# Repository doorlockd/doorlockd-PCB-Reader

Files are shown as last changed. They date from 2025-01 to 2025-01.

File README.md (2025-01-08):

# Doorlockd card reader
This repository contains the design for a small PCB for an NFC card
reader to be used with the doorlockd door access system.

The PCB stacks on top of the the [Elechouse PN532 NFC reader
board](https://www.elechouse.com/product/pn532-nfc-rfid-module-v4/) and
adds indicator LEDs and a four-pin connector for a UART connection to
a controller.

This PCB is designed to be used with the [doorlockd hardware and
software](https://github.com/doorlockd/), but can also be used with any
other controller that can provide 5V and can talk over a UART.

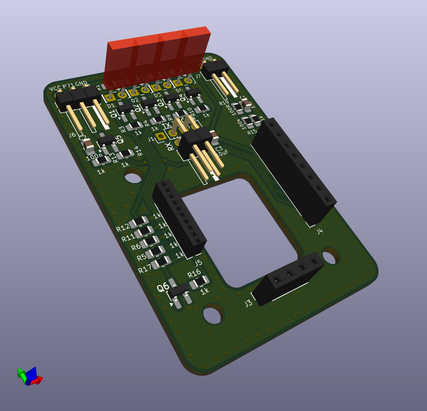
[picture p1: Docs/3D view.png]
3D rendering of PCB


In addition to the PCB, a 3D-printed case was made. Design files for
that will hopefully be published later.

See the [doorlockd organization page](https://github.com/doorlockd/) for
some photographs of the card reader PCB in practice.

## Features
This PCB provides:

 - UART connection the the PN532 board, using a square (2x2) connector
   with standard 2.54mm pitch. The square connector makes it easy to
   feed the cable through a round hole in e.g. a door frame.
 - Four indicator LEDs.
 - One open-drain output pin, to control external LEDs, a solenoid, etc.
 - One input pin, to read an external button, switch, etc.

The LEDs, output and input pin are driven/read by I/O pins on the PN532
NFC chip and can be individually controlled/read by sending the proper
commands via UART.

## License
Copyright 2021-2025 Matthijs Kooijman (matthijs@stdin.nl)

This source describes Open Hardware and is licensed under the CERN-OHL-P
v2 or any later version.

You may redistribute and modify this documentation and make products
using it under the terms of the CERN-OHL-P v2 (https:/cern.ch/cern-ohl).

This documentation is distributed WITHOUT ANY EXPRESS OR IMPLIED
WARRANTY, INCLUDING OF MERCHANTABILITY, SATISFACTORY QUALITY AND FITNESS
FOR A PARTICULAR PURPOSE. Please see the CERN-OHL-P v2 for applicable
conditions

See LICENSE.txt for the full license text.

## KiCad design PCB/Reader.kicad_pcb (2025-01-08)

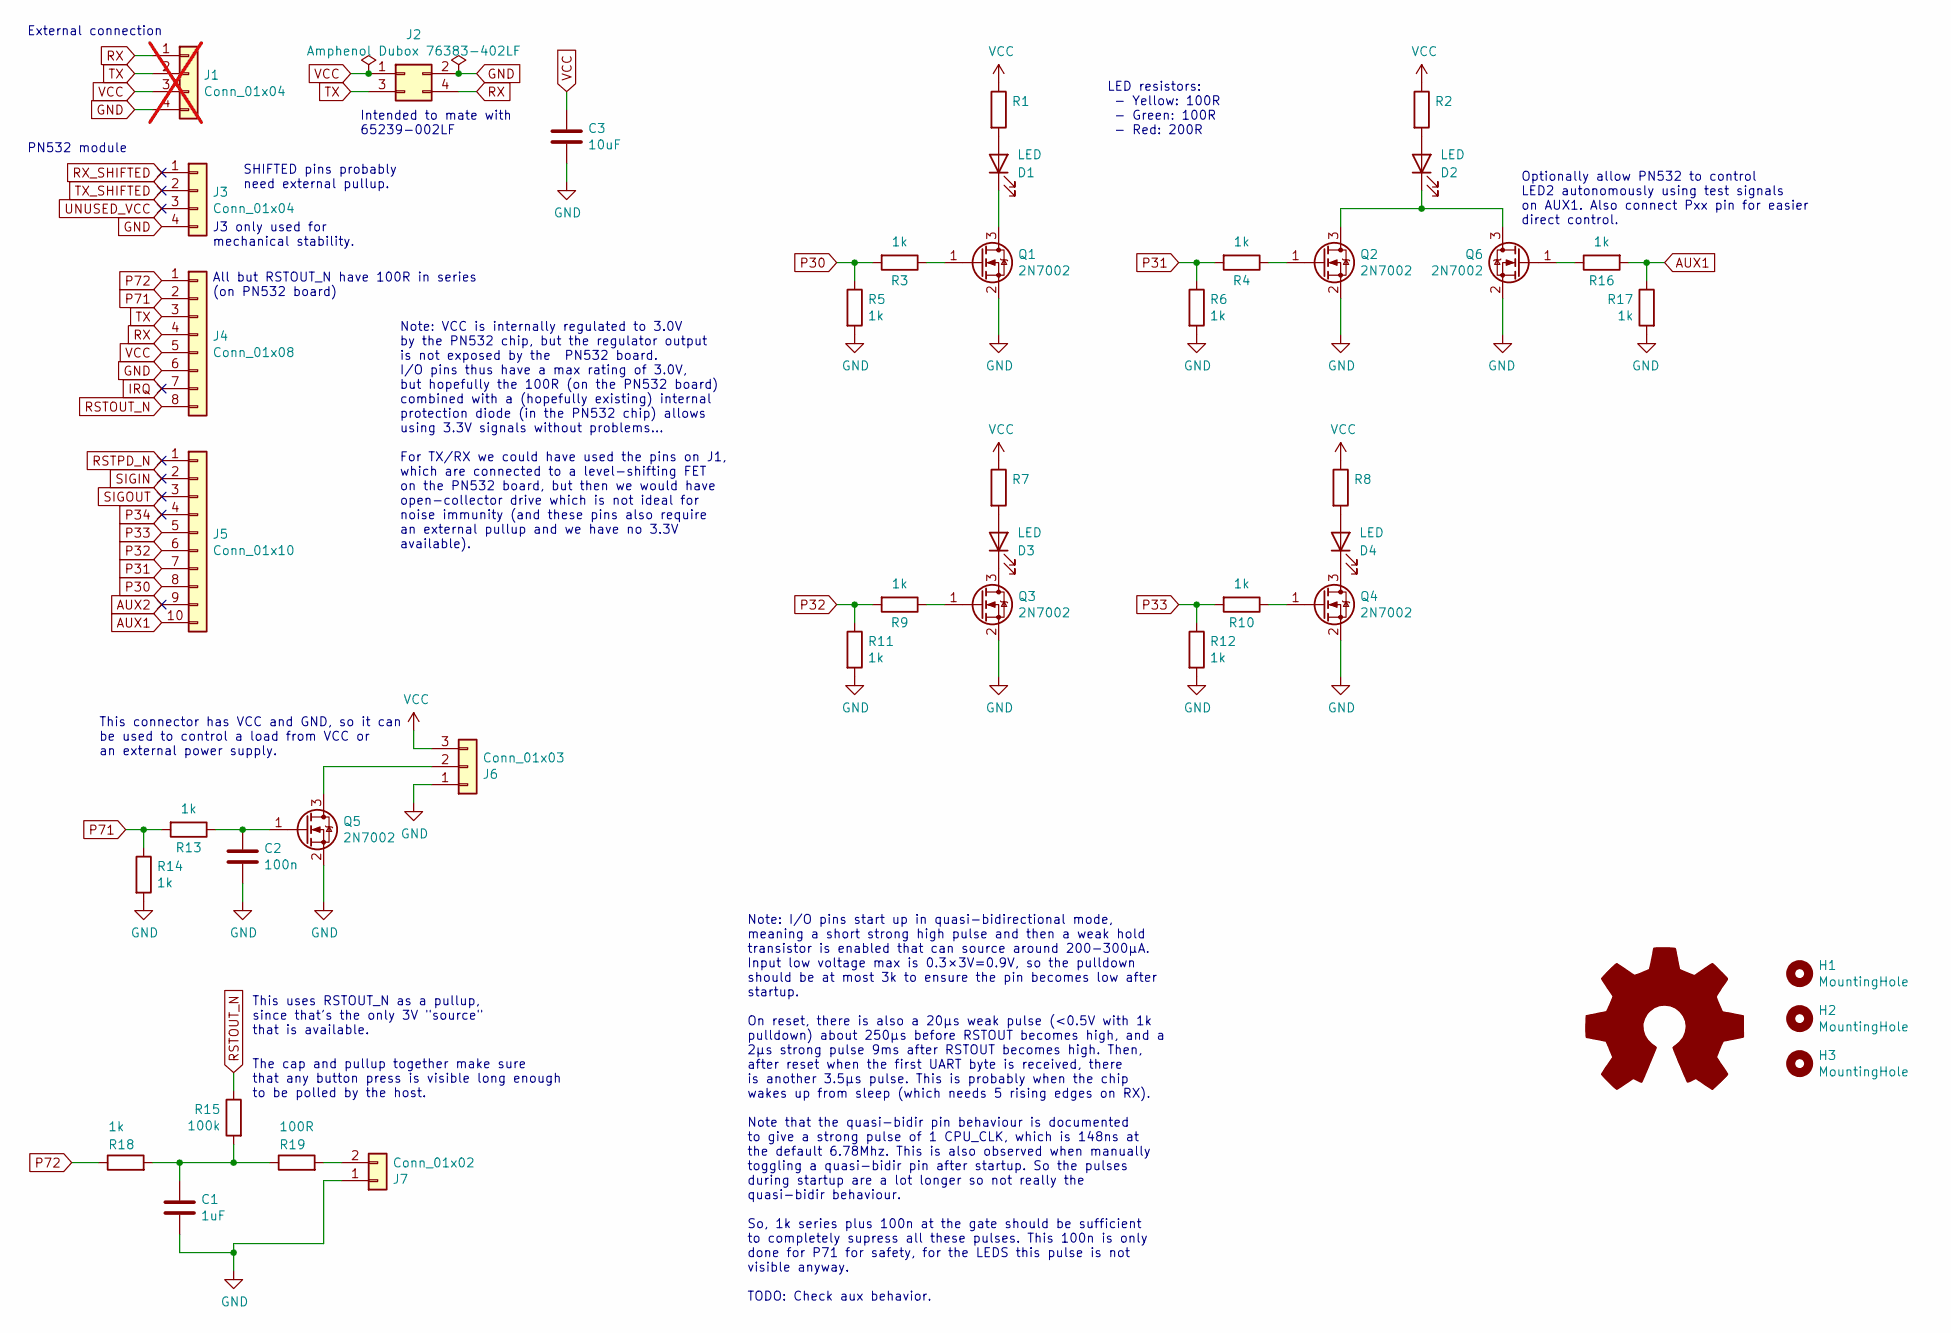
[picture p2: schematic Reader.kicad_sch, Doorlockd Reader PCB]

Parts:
C1: 1uF; C_0805_2012Metric_Pad1.18x1.45mm_HandSolder
C2: 100n; C_0805_2012Metric_Pad1.18x1.45mm_HandSolder
C3: 10uF; C_0805_2012Metric_Pad1.18x1.45mm_HandSolder
D1, D2, D3, D4: LED; LED_Rectangular_W5.0mm_H2.0mm
H1, H2, H3: MountingHole; MountingHole_3.2mm_M3
J1: Conn_01x04; PinHeader_1x04_P2.54mm_Vertical; not fitted
J2: Amphenol Dubox ‎76383-402LF‎; PinHeader_2x02_P2.54mm_Horizontal
J3: Conn_01x04; PinSocket_1x04_P2.54mm_Vertical
J4: Conn_01x08; PinSocket_1x08_P2.54mm_Vertical
J5: Conn_01x10; PinSocket_1x10_P1.27mm_Vertical
J6: Conn_01x03; PinHeader_1x03_P2.54mm_Horizontal
J7: Conn_01x02; PinHeader_1x02_P2.54mm_Horizontal
LOGO1: Logo_Open_Hardware_Large; OSHW-Symbol_8.9x8mm_SilkScreen
Q1, Q2, Q3, Q4, Q5, Q6: 2N7002; SOT-23_Handsoldering
R1, R2, R7, R8: R_0805_2012Metric_Pad1.20x1.40mm_HandSolder
R3, R4, R5, R6, R9, R10, R11, R12, R13, R14, R16, R17, R18: 1k; R_0805_2012Metric_Pad1.20x1.40mm_HandSolder
R15: 100k; R_0805_2012Metric_Pad1.20x1.40mm_HandSolder
R19: 100R; R_0805_2012Metric_Pad1.20x1.40mm_HandSolder

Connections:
AUX1: J5.10, R16.2, R17.1
AUX2: J5.9
GND: C1.2, C2.2, C3.2, J1.4, J2.2, J3.4, J4.6, J6.1, J7.1, Q1.2 (S), Q2.2 (S), Q3.2 (S), Q4.2 (S), Q5.2 (S), Q6.2 (S), R5.2, R6.2, R11.2, R12.2, R14.2, R17.2
IRQ: J4.7
unnamed: C1.1, R15.2, R18.2, R19.1
unnamed: D1.2 (A), R1.2
unnamed: D1.1 (K), Q1.3 (D)
unnamed: D2.2 (A), R2.2
unnamed: D2.1 (K), Q2.3 (D), Q6.3 (D)
unnamed: D3.2 (A), R7.2
unnamed: D3.1 (K), Q3.3 (D)
unnamed: D4.2 (A), R8.2
unnamed: D4.1 (K), Q4.3 (D)
unnamed: J6.2, Q5.3 (D)
unnamed: J7.2, R19.2
unnamed: Q1.1 (G), R3.1
unnamed: Q2.1 (G), R4.1
unnamed: Q3.1 (G), R9.1
unnamed: Q4.1 (G), R10.1
unnamed: C2.1, Q5.1 (G), R13.1
unnamed: Q6.1 (G), R16.1
P30: J5.8, R3.2, R5.1
P31: J5.7, R4.2, R6.1
P32: J5.6, R9.2, R11.1
P33: J5.5, R10.2, R12.1
P34: J5.4
P71: J4.2, R13.2, R14.1
P72: J4.1, R18.1
RSTOUT_N: J4.8, R15.1
RSTPD_N: J5.1
RX: J1.1, J2.4, J4.4
RX_SHIFTED: J3.1
SIGIN: J5.2
SIGOUT: J5.3
TX: J1.2, J2.3, J4.3
TX_SHIFTED: J3.2
UNUSED_VCC: J3.3
VCC: C3.1, J1.3, J2.1, J4.5, J6.3, R1.1, R2.1, R7.1, R8.1

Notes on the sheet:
This connector has VCC and GND, so it can be used to control a load from VCC or an external power supply.
Note: VCC is internally regulated to 3.0V by the PN532 chip, but the regulator output is not exposed by the PN532 board. I/O pins thus have a max rating of 3.0V, but hopefully the 100R (on the PN532 board) combined with a (hopefully existing) internal protection diode (in the PN532 chip) allows usi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
LED resistors: - Yellow: 100R - Green: 100R - Red: 200R
Optionally allow PN532 to control LED2 autonomously using test signals on AUX1. Also connect Pxx pin for easier direct control.
This uses RSTOUT_N as a pullup, since that's the only 3V "source" that is available.
PN532 module
SHIFTED pins probably need external pullup.
The cap and pullup together make sure that any button press is visible long enough to be polled by the host.
Note: I/O pins start up in quasi-bidirectional mode, meaning a short strong high pulse and then a weak hold transistor is enabled that can source around 200-300μA. Input low voltage max is 0.3×3V=0.9V, so the pulldown should be at most 3k to ensure the pin becomes low after startup. On reset, there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
J3 only used for mechanical stability.
Intended to mate with 65239-002LF
All but RSTOUT_N have 100R in series (on PN532 board)
External connection

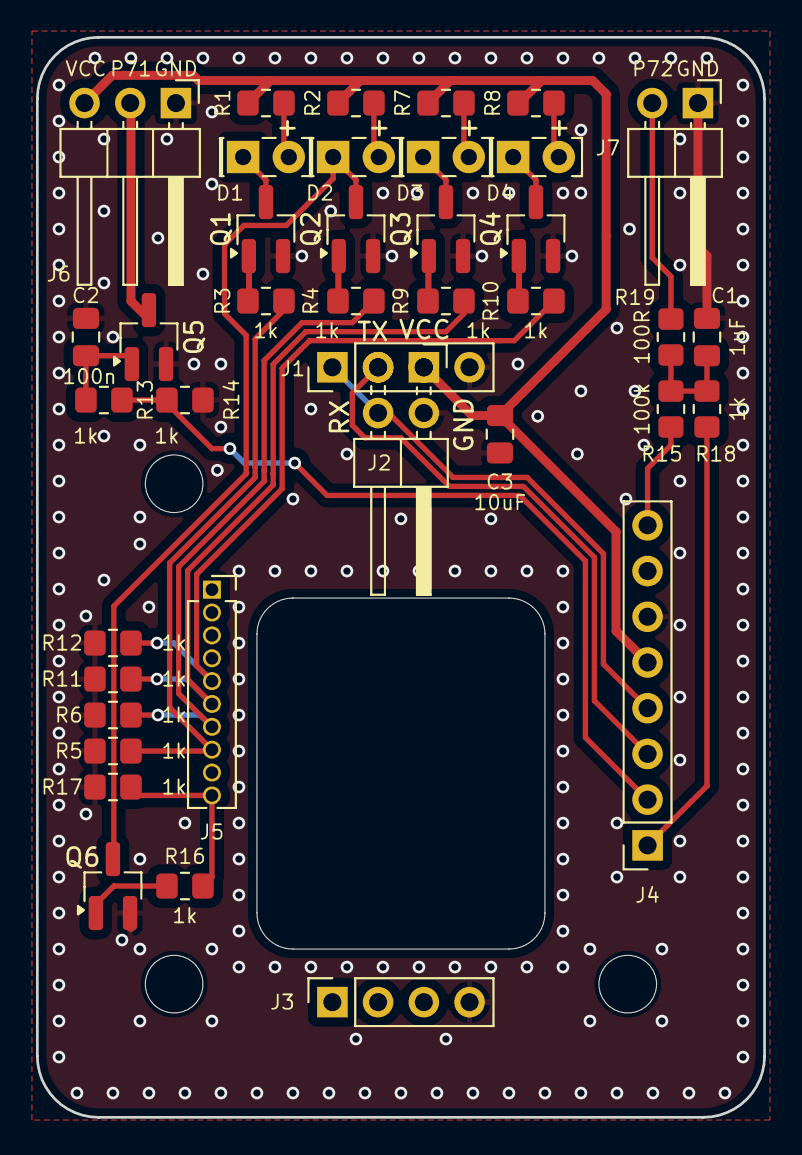
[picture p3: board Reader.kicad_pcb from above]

Board: 2 copper layers, 40.4 x 60.0 mm, 43 parts (1 on the bottom side), 29 nets.

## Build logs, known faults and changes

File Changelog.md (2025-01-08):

DoorlockCardreader version 1.0, components 2025-01-08
=====================================================
 - Added C2 on Q5 gate to suppress startup pulse on PN532 P71 pin.
 - Added R18 and R19 in series with the P72 input pin.
 - Removed optional from pulldowns, made value 1k
 - Enlarged mounting holes from 2.5mm to 3.2mm
 - Marked LED polarity on silkscreen
 - Reduced overly wide thermal reliefs due to wide GND traces
 - Added C3 as input supply buffer cap
 - Change to hand soldering footprints for transistors
 - Clean up Fab and silkscreen layers
 - Small layout and via improvements
 - Slightly enlarge silkscreen text to comply with Aisler design rules.
 - Update PCB name and revision in silkscreen
 - Added LED resistor value lookup table in silkscreen.

doorlockd-cardreader version 0.1
================================
 - Initial version.

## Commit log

2021-02-20 Add initial version v0.1
    [Reader.kicad_pcb, Reader.sch]
2023-06-06 Update schematic to KiCad 7
    This also sets the edge clearance to 0,5mm. This is a new setting, that
    was previously set using edge cuts line widths and/or zone clearance
    settings. This commit also refills the zones, which are slightly bigger
    than before.
    This also removes the old .sch and .pro file, which are replaced by
    .kicad_sch and .kicad_pro, and removes the lib cache, which is no longer
    used in the new schematic format.
    [Reader.kicad_pcb, Reader.kicad_sch, Reader.sch]
2023-06-06 Add board name and version to front silkscreen
    [Reader.kicad_pcb]
2023-06-06 Make some schematic changes
    This adds some notes, updates some component values to the actually used
    values, and maybe some other small changes.
    [Reader.kicad_sch]
2024-01-23 Update PCB from schematic
    This makes no actual changes, just lets KiCad pull in changes (probably
    mostly udpated footprints and renumbered symbols, and maybe some KiCad
    upgrade changes too).
    [Reader.kicad_pcb]
2024-01-23 Add 100n capacitor on output pin
    This takes care of suppressing the startup pulse given by the PN532.
    [Reader.kicad_pcb, Reader.kicad_sch]
2024-01-23 Add series resistors for button input
    [Reader.kicad_pcb, Reader.kicad_sch]
2024-02-03 Remove duplicate TODO
    [Reader.kicad_sch]
2024-02-06 Enlarge mounting holes
    [Reader.kicad_pcb, Reader.kicad_sch]
2024-02-06 Remove groundloop-related todos
    It seems that having multiple GND connections and a hole inside the GND
    plane might not actually be problematic (or if it is, making a horseshoe
    out of it might not make it better).
    So for now, leave this as is until it is actually a problem.
    [Reader.kicad_sch]
2024-02-06 Mark LED polarity on silkscreen
    [Reader.kicad_pcb, Reader.kicad_sch]
2024-02-06 Remove unintended silkscreen line
    [Reader.kicad_pcb, Reader.kicad_sch]
2024-02-06 Reduce overly wide thermal reliefs due to wide GND traces
    The thermal relief spoke width was 0,3mm, but there were also explicit
    GND traces of 0,5mm that made some components (esp C1 and some
    transistors) hard to solder. This reduces the trace width to 0,3mm,
    hopefully alleviating this issue.
    [Reader.kicad_pcb, Reader.kicad_sch]
2024-02-06 Add input supply buffer cap
    [Reader.kicad_pcb, Reader.kicad_sch]
2024-02-06 Use hand soldering footprints for transistors
    [Reader.kicad_pcb, Reader.kicad_sch]
2024-02-06 Clean up Fab layer
    [Reader.kicad_pcb]
2024-05-28 Improve silkscreen layout
    This also moves some vias, locks some footprints and maybe makes some more changes.
    [Reader.kicad_pcb]
2024-05-28 Update to KiCad 8
    This is the result of opening the project, schematic and board and the
    schematic setup and board setup dialogs (and clicking open each section)
    without making any changes. In addition, a zone fill is done.
    This commit changes all files completely, since the new KiCad adds more
    linebreaks to the files it writes.
    [Reader.kicad_pcb, Reader.kicad_sch]
2024-05-28 Add changelog file
    [Reader.kicad_sch]
2024-05-28 Move PCB files into new PCB subdirectory
    This gives a bit more structure to the repository and prepares for
    adding some workflow integration.
    [Reader.kicad_pcb, Reader.kicad_sch]
2024-10-09 PCB-workflows: Add submodule
2024-10-09 Set up PCB workflow
    This is the result of running
    `./PCB-workflows/tools/setup-project-repo.sh PCB/Reader.kicad_pro` and
    then changing the page setup to use the drawing sheet without 3devo
    logo.
    [Reader.kicad_pcb]
2024-10-09 ERC: Update schematic symbols from library
    [Reader.kicad_sch]
2024-10-09 ERC: Add NC flags for unused pins
    [Reader.kicad_sch]
2024-10-09 ERC: Add power flag for GND and VCC inputs
    This fixes the last ERC errors
    [Reader.kicad_sch]
2024-10-09 DRC: Enlarge smallest silkscreen text
    The board setup, based on Aisler specifications, has minimum 0.8mm
    height for text. This changes most text that uses 0.75mm to use 0.8mm
    instead. No text is moved, this just enlarges the text slightly (by
    manually editing the kicad_pcb file).
    [Reader.kicad_pcb]
2024-10-09 More KiCad 8 updates to project file
    These were written by KiCad 8 after opening the board contstraints and
    adding some DRC exceptions (so either of those triggered this).
2024-10-09 DRC: Ignore overlapping courtyards and silkscreen
    This is a tiny PCB, so there are a dozen of overlapping courtyards and
    silkscreen that are acceptable and unavoidable, so just ignore all of them.
2024-10-09 DRC: (Re)move two vias
    Seems tracks were moved over/near these vias, producing a short and
    clearance failure. This removes one via and moves the other.
    [Reader.kicad_pcb]
2024-10-09 DRC: Update footprints from library
    [Reader.kicad_pcb]
2024-10-09 DRC: Exclude three GND pins with too few thermals
    These have a good connection on the bottom, just too little connection
    on the top, but since there is little GND plane on the top to connect
    to, this is not an issue.
2024-10-09 DRC: Ignore two overlapping hole warnings
    This is from two footprints that intentionally overlap, so this is ok.
    Note that when running DRC with KiCad 8.0.2, these exceptions seem to be
    dropped and these errors re-occur for some reason. This is probably
    a KiCad bug.
2024-10-09 DRC: Remove random silkscreen lines
    [Reader.kicad_pcb]
2025-01-07 DRC: Slightly reduce center hole size
    This ensures the connector silkscreen is not cut off by the board edge,
    fixing a bunch of DRC warnings.
    [Reader.kicad_pcb]
2025-01-07 Move schematic note onto page
    [Reader.kicad_sch]
2025-01-07 Improve some schematic notes
    [Reader.kicad_sch]
2025-01-07 Small layout and via improvements
    This also makes some changes that are likely because of using a slightly
    newer KiCad version.
    [Reader.kicad_pcb]
2025-01-07 Improve revision silk and re-add OSHW logo
    The logo got removed at some point, so re-add it.
    Remove the PCB name on the front in favor of the silk on the back where
    there is more room.
    Match the PCB name to the git repo name, and auto-fill the board
    revision.
    [Reader.kicad_pcb, Reader.kicad_sch]
2025-01-07 Add note about not using the level shifted pins
    [Reader.kicad_sch]
2025-01-07 Replace LED resistor values with lookup table
    [Reader.kicad_pcb, Reader.kicad_sch]
2025-01-07 Update PCB from schematic
    This makes some property changes, but does not update anything
    functionally.
    [Reader.kicad_pcb]
2025-01-08 PCB-workflows: Update
    This includes the following commits:
    89ca71b Workaround kibot issue that causes build to fail
    add74d3 Switch to KiCad 8 erc/drc checks
    032b730 Grant permissions to create releases
    6fca111 Remove outdated comment
    ff02ff5 Generate gerbers and drill files for JLPCB
    5165ca9 Include project files in outputs
2025-01-08 Improve dimension annotations
    This is mostly layout fixes (fix overlapping numbers, smaller arrows and
    less decimals), but also fixes the annotation of the center cutout which
    was a little misaligned, probably after commit a628468 (DRC: Slightly
    reduce center hole size, 2024-07-09).
    [Reader.kicad_pcb]
2025-01-08 Do a zone fill
    Seems some (subtle?) copper changes were not applied in some earlier
    commit.not applied in some earlier commit.not applied in some earlier
    commit.not applied in some earlier commit.
    [Reader.kicad_pcb]
2025-01-08 Use CERN-OHL-P v2+ license
    [Reader.kicad_pcb, Reader.kicad_sch]
2025-01-08 Mark 4-pin J1 pin header as DNP
    This pin header is an alternative for the J2 2x2 pin connector and the
    footprint is added just in case, but normally only J2 should be used.
    [Reader.kicad_pcb, Reader.kicad_sch]
2025-01-08 Add some (estethic) structure to the schematic
    [Reader.kicad_sch]

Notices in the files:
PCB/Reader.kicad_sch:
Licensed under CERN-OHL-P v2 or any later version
